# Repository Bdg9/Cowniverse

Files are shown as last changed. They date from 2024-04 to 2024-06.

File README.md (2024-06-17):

# Cowniverse

Welcome to the **Cowniverse** documentation! This prototype originated from the Interactive Game for Children project from the Assistive Technology Challenge. It involves creating a fun game to foster interactions between children with cerebral palsy. The repository is structured into several key components, which are organized into different folders. Below you will find a detailed overview of the contents of each folder.

## Folder Structure

1. **full**
2. **fusion**
3. **library**
4. **test**

### Full Folder

The `full` folder contains the code for the completed prototypes.

- **Prototype 1**: The first complete prototype. This includes all necessary code to run this version.
- **Prototype 2**: The second complete prototype. Similar to Prototype One, this includes all the required code.

### Fusion Folder

The `fusion` folder houses all the CAD files for the different parts of prototype 2. These files can be used for 3D printing or laser cutting the necessary components for the prototype.

- **3d_printed_mounts**: CAD files for the main electronics mounts and the speakers, to 3D print.
- **Box buttons**: CAD files for buttons boxes, to laser cut.
- **Farm**: CAD files for building the farm, to laser cut.
- **Game board**: CAD files for the rounded box, the PET sheet between magnorail and the character and the fixations to close the box, to laser cut.
- **Gate**: CAD files for the gate. The mount for the servos, to laser cut. The sliding mechanism and the mount for the post, to 3d print.
- **Snowboard**: CAD files for snowboards/skates to place the finger puppet on it or a figurine, to 3d print.

### Library Folder

The `library` folder includes the necessary libraries to be installed for the `df_player pro`, which is used in prototype 2. Ensure you install these libraries before running the final prototype.

- **DFPlayer Pro Library**: Download and install this library to ensure proper functionality of the audio components in the prototypes.

### Test Folder

The `test` folder contains Arduino scripts used to test various subsystems of the prototypes. These scripts are helpful for debugging and ensuring each individual subsystem works correctly before integrating them into the full prototypes.

## Contact

For any questions or further information, please contact us one of us :
- Gonçalo Braga : [gbraga2086@gmail.com]
- Barbara De Groot : [irado1999@gmail.com] 
- Loric Emmenegger : [emmenegger.loric@gmail.com]
- Jean-Baptiste Poussin : [poussin.jeanbaptiste@gmail.com]

Happy coding, and welcome to the Cowniverse!

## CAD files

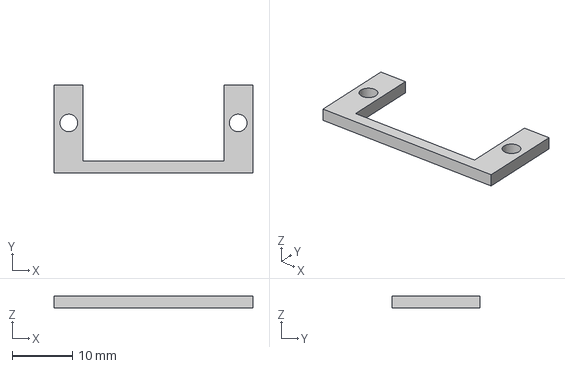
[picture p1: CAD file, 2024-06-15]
fusion/Gate/servo_mount_house.step
32.9 x 14.5 x 2.00 mm

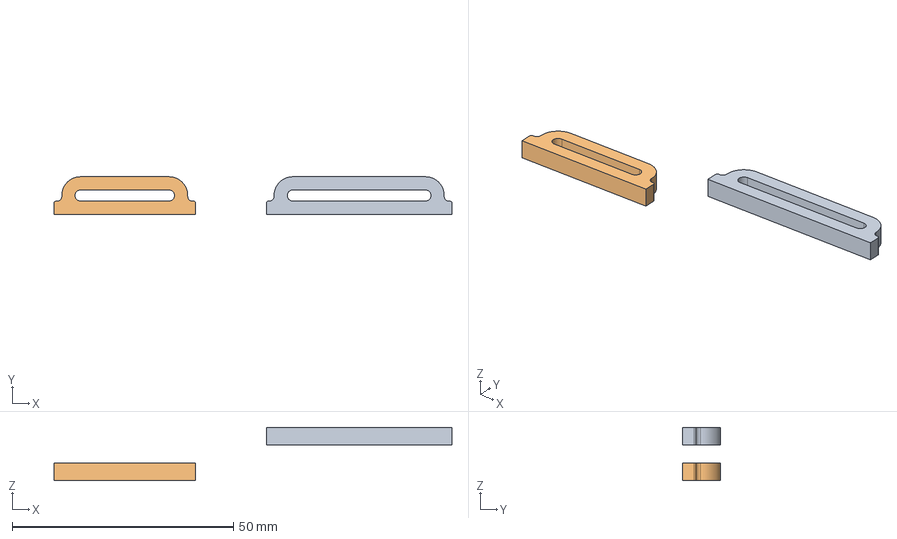
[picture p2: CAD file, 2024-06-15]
fusion/Gate/servo_slide.step
90.0 x 8.50 x 12.0 mm

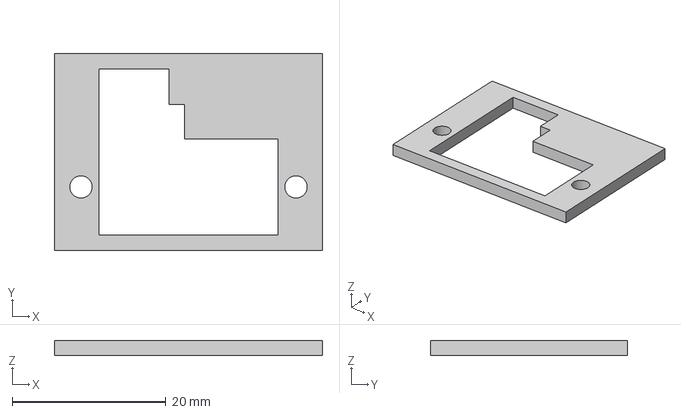
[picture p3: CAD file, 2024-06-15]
fusion/Gate/servo_mount_post.step
34.9 x 25.6 x 2.00 mm

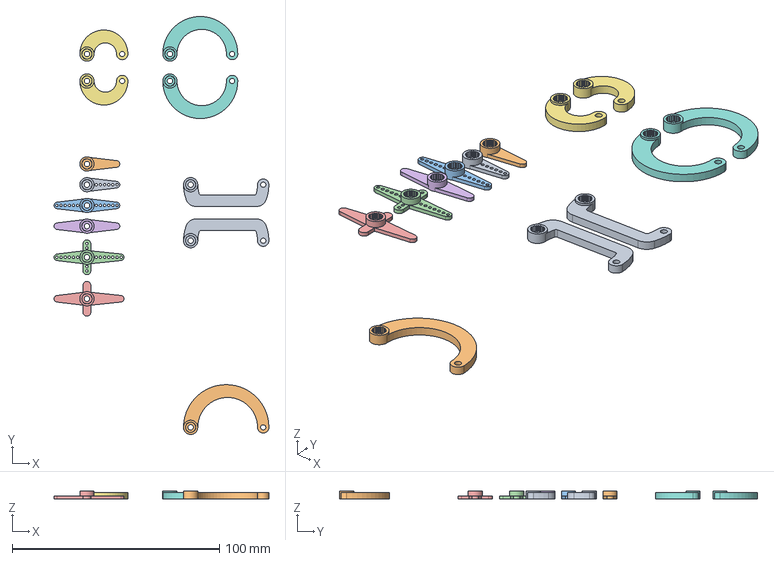
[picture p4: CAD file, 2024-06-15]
fusion/Gate/SG90_Servo_Horn.step
103.6 x 201.6 x 3.82 mm

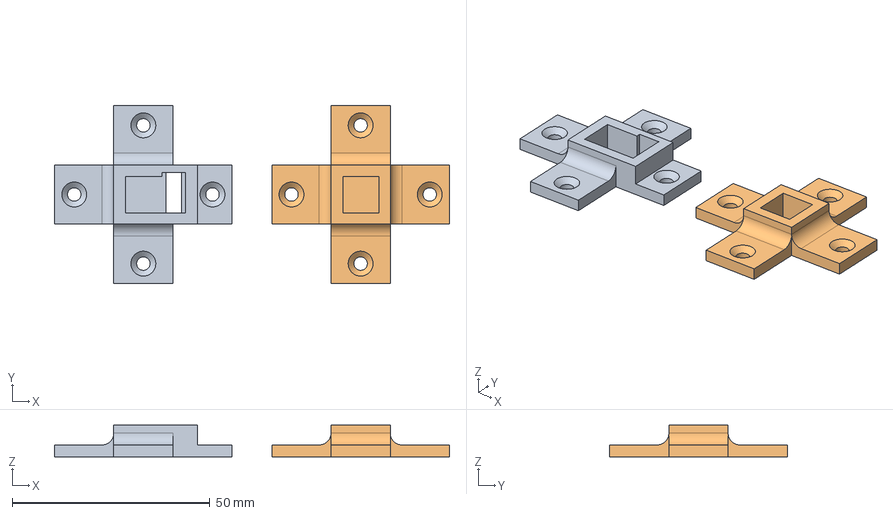
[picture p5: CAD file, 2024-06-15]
fusion/Gate/post_mount.step
100.0 x 45.0 x 8.00 mm

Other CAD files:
fusion/Box buttons/box double button.step
fusion/Game board/Rounded Box/RoundedBox sides.step
fusion/Box buttons/box single button.step
fusion/Game board/MDF_PET_support.step
fusion/Game board/Rounded Box/RoundedBox top.step
fusion/Game board/PET_path.step
fusion/Game board/Rounded Box/RoundedBox bottom.step
fusion/Game board/External_support_grass.step
fusion/Game board/nut_fixation_test.step
fusion/3d_printed_mounts/mount_all.f3d
fusion/3d_printed_mounts/speaker_mount.f3d
fusion/Box buttons/box double button.f3d
fusion/Box buttons/box single button.f3d
fusion/Box buttons/box_engravings.f3d
fusion/Farm/enseignes.f3d
fusion/Farm/mount_farm.f3d
fusion/Farm/servo_mount_farm.f3d
fusion/Farm/socle_toit.f3d
fusion/Farm/toit-dup.f3d
fusion/Farm/toit.f3d
fusion/Farm/toit_maison.f3d
fusion/Game board/External_support_grass.f3d
fusion/Game board/MDF_PET_support.f3d
fusion/Game board/PET_path.f3d
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

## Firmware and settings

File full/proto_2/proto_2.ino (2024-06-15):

#include <Servo.h>
#include "Obstacle.h"
#include "States.h"
#include "House.h"
//librairy audio
#include <DFRobot_DF1201S.h>
//librairy leds
#include <Adafruit_NeoPixel.h>

// Define the motor control pins
#define ENA 6
#define IN1 8
#define IN2 7
#define SPEED 90

// Define buttons pin
#define B_FORWARD 32
#define B_BACKWARD 33
#define B_OBS 34
#define POT A10
#define MODE_1 2
#define MODE_2 3

// Define servos pin
#define BAR_1 11
#define BAR_2 10
#define HOUSE_L 13
#define HOUSE_R 12 

// Define for leds
#define LED_PIN     5     // Pin connecté à la bande de LEDs
#define LED_COUNT   8    // Nombre de LEDs dans la bande
#define BRIGHTNESS 50

//file paths for audio
const char* file_paths_meuh[] = {
    "/meuh/Meuh1.mp3",
    "/meuh/Meuh2.mp3",
    "/meuh/Meuh3.mp3",
    "/meuh/Meuh4.mp3",
    "/meuh/Meuh5.mp3",
    "/meuh/Meuh6.mp3",
    "/meuh/Meuh7.mp3",
    "/meuh/Meuh8.mp3",
};

const char* file_paths_bip[] = {
  "/bipbip/Bip1.mp3",
  "/bipbip/Bip2.mp3",
  "/bipbip/Bip3.mp3",
  "/bipbip/Bip4.mp3",
  "/bipbip/Bip5.mp3",
  "/bipbip/Bip6.mp3",
};

const char* file_paths_groin[] = {
  "/groin/Groin1.mp3",
  "/groin/Groin2.mp3",
  "/groin/Groin3.mp3",
  "/groin/Groin4.mp3",
  "/groin/Groin5.mp3",
  "/groin/Groin6.mp3",
  "/groin/Groin7.mp3",
};

const char* file_paths_cot[] = {
  "/poule/Poule5.mp3",
  "/poule/Poule4.mp3",
  "/poule/Poule3.mp3",
  "/poule/Poule2.mp3",
  "/poule/Poule1.mp3",
};

const char* file_paths_yay[] = {
  "/marley/marley1.mp3",
  "/yay/Hiphoura2.mp3",
  "/yay/Houra1.mp3",
  "/yay/titu.mp3",
  "/yay/Uhou1.mp3",
  "/yay/uhouai.mp3",
  "/yay/uhu.mp3",
  "/yay/vamos.mp3",
  "/yay/Yay1.mp3",
  "/yay/Yay2.mp3",
  "/yay/Yay3.mp3",
  "/yay/Yay4.mp3",
  "/yay/Youpi1.mp3",
  "/yay/Youpi2.mp3",
  "/marley/marley1.mp3",
  "/ohNo/Ohoh1.mp3",
};

const int num_files_meuh = sizeof(file_paths_meuh) / sizeof(file_paths_meuh[0]);
const int num_files_bip = sizeof(file_paths_bip) / sizeof(file_paths_bip[0]);
const int num_files_groin = sizeof(file_paths_groin) / sizeof(file_paths_groin[0]);
const int num_files_yay = sizeof(file_paths_yay) / sizeof(file_paths_yay[0]);
const int num_files_cot = sizeof(file_paths_cot) / sizeof(file_paths_cot[0]);

//debug prints
bool verbose = false;

// Initialiser DFPlayer
DFRobot_DF1201S DF1201S;
int vol;

// Init leds
Adafruit_NeoPixel strip = Adafruit_NeoPixel(LED_COUNT, LED_PIN, NEO_GRB + NEO_KHZ800);


//left door
Servo bar_1_servo;
Obstacle bar_1(bar_1_servo);

//right door
Servo bar_2_servo;
Obstacle bar_2(bar_2_servo);

//house
Servo house_1;
Servo house_2;
House house(house_1, house_2);

//obstacle button
int buttonObsState = LOW;
int buttonObsLastState = LOW;
bool buttonObs = false;

//motor forward button
int buttonForwState = LOW;
int buttonForwLastState = LOW;

//motor backward button
int buttonBackState = LOW;
int buttonBackLastState = LOW;

//motor state
MotorState motorState = STOP;
Sound sound = NONE;
bool bar_1_update = false;
bool bar_2_update = false;
bool house_update = false;

//game mode 
GameMode mode;
Sound character_type;

//detection timer
unsigned long detection_timer = 0;
const unsigned long detection_interval = 500;

void setup() {
  Serial.begin(9600);
  Serial3.begin(115200); //begin serial for audio

  //init gates
  bar_1.init(BAR_1, A1, A0, 50, 165);
  bar_2.init(BAR_2, A3, A2, 165, 50);

  //init house
  house.init(HOUSE_L, HOUSE_R, A4, 60, 10, 8, 50);

  // Set the buttons pin as outputs
  pinMode(B_OBS, INPUT);
  pinMode(B_FORWARD, INPUT);
  pinMode(B_BACKWARD, INPUT);
  pinMode(POT, INPUT);
  pinMode(MODE_1, INPUT_PULLUP);
  pinMode(MODE_2, INPUT_PULLUP);

  // Set the motor control pins as outputs
  pinMode(ENA, OUTPUT);
  pinMode(IN1, OUTPUT);
  pinMode(IN2, OUTPUT);

  //init game mode
  mode = read_mode();

  //choose character type
  int mode_1 = digitalRead(MODE_1);
  int mode_2 = digitalRead(MODE_2);
  if((mode_1 == HIGH) && (mode_2 == HIGH)){
    character_type = COW;
  }else if(mode_2 == HIGH){
    character_type = PIG;
  }else{
    character_type = COT;
  }

  // Set up leds
  strip.begin();
  strip.show(); // Initialise toutes les LEDs à 'off'
  strip.setBrightness(BRIGHTNESS);


  //setup audio
  // Initialisation du DFPlayer
  while(!DF1201S.begin(Serial3)){
    Serial.println("Init failed, please check the wire connection!");
    delay(1000);
  }

  Serial.println("audio ready");
  Serial.print("mode :");
  Serial.println(mode);
  
  //Set volume to 15
  DF1201S.setVol(20);
  //deactivate prompts
  DF1201S.setPrompt(false);
  //Enter music mode
  DF1201S.switchFunction(DF1201S.MUSIC);
  //Set playback mode to "repeat all"
  DF1201S.setPlayMode(DF1201S.SINGLE);

  delay(500);

  //test sensor
  if( (bar_1.get_front_sensor() > THRESHOLD) ||  (bar_1.get_back_sensor() > THRESHOLD) || (bar_2.get_front_sensor() > THRESHOLD) ||
      (bar_2.get_back_sensor() > THRESHOLD) || (house.get_sensor() > THRESHOLD)){
    Serial.println("ERROR : sensor obstructed");
    DF1201S.playFileNum(/*File Number = */2);
    delay(10000);
  }

  DF1201S.playFileNum(/*File Number = */1);
  delay(200);

  
}

void loop() {
  //change volume
  vol = analogRead(POT);            // reads the value of the potentiometer (value between 0 and 1023)
  vol = map(vol, 0, 1023, 0, 30);     // scale it for use with the servo (value between 0 and 180)
  DF1201S.setVol(/*VOL = */vol);

  //change mode
  mode = read_mode();
  
  // check button
  buttonObsState = digitalRead(B_OBS);
  buttonForwState = digitalRead(B_FORWARD);
  buttonBackState = digitalRead(B_BACKWARD);
  
  /*
  //use serial instead of physical buttons
  if (Serial.available() > 0) {
    String receivedText = Serial.readStringUntil('\n'); // Read the incoming data until newline character

    receivedText.trim(); // Remove any leading/trailing whitespace characters
    
    if (receivedText == "f") {
      buttonForwState = HIGH;
    } else if (receivedText == "b") {
      buttonBackState = HIGH;
    } else if (receivedText == "o") {
      buttonObsState = HIGH;
      sound = YAY;
    } else {
      Serial.println("Unknown command: " + receivedText);
    }
  }else{
    buttonObsState = LOW;
    buttonForwState = LOW;
    buttonBackState = LOW;
  }*/

  // check if the button is pressed
  if (buttonObsLastState != buttonObsState){
    if (buttonObsState == HIGH){
      buttonObs = true;
      sound = BIP;
    }
  }else{
    buttonObs = false;
  }

  if (buttonForwLastState != buttonForwState){
    if (buttonForwState == HIGH){
      motorState = FORWARD;
      sound = character_type;
    }
  }

  if (buttonBackLastState != buttonBackState){
    if (buttonBackState == HIGH){
      motorState = BACKWARD;
    }
  }

  //update buttons state
  buttonObsLastState = buttonObsState;
  buttonForwLastState = buttonForwState;
  buttonBackLastState = buttonBackState;


  //update the obstacles
  if (mode == SLOW){
    bar_1_update = bar_1.update(buttonObs, motorState);
    bar_2_update = bar_2.update(buttonObs, motorState);
    house_update = house.update(buttonObs, motorState);

    //stop motors if player is detected and the obstacle is closed
    if ((bar_1_update && !bar_1.get_state()) || (bar_2_update && !bar_2.get_state()) || (house_update && !house.get_state()) || (!house.get_state())){
      motorState = STOP;
    }
  }else{
    bar_1_update = bar_1.update_continuous(buttonObs, motorState);
    bar_2_update = bar_2.update_continuous(buttonObs, motorState);
    house_update = house.update_continuous(buttonObs);
  }

  if (house_update){
    sound = YAY;
  }

  //update leds
  if(bar_1_update || bar_2_update || house_update){
    strip.fill(strip.Color(255, 0, 0)); // Red color
  }else if(DF1201S.getFileName() == "/marley/marley1.mp3"){
    setPattern();
  }else{
    strip.fill(strip.Color(0, 255, 0)); // Green color
  }

  strip.show();
  

  if (verbose){
    //Serial.println(house.get_state());
    /*Serial.print("mode 1 :");
    Serial.print(digitalRead(MODE_1));
    Serial.print("  mode_2 : ");
    Serial.println(digitalRead(MODE_2));*/
    Serial.print("A0 : ");
    Serial.print(analogRead(A0));
    Serial.print("  ");
    Serial.print("A1 : ");
    Serial.print(analogRead(A1));
    Serial.print("  ");
    Serial.print("A2 : ");
    Serial.print(analogRead(A2));
    Serial.print("  ");
    Serial.print("A3 : ");
    Serial.print(analogRead(A3));
    Serial.print("  ");
    Serial.print("A10 : ");
    Serial.print(analogRead(A4));
    Serial.println("  ");
  }

  //update the motors
  

  switch (motorState) {
    case FORWARD:
      analogWrite(ENA, SPEED);
      digitalWrite(IN1, HIGH);
      digitalWrite(IN2, LOW);
      break;
    case BACKWARD:
      analogWrite(ENA, SPEED);
      digitalWrite(IN1, LOW);
      digitalWrite(IN2, HIGH);
      break;
    case STOP:
    default:
      digitalWrite(IN1, LOW);
      digitalWrite(IN2, LOW);
      break;
  }
  
  switch (sound){
    case COT:
      playRandomSong(file_paths_cot, num_files_cot);
      sound = NONE;
      break;
    case PIG:
      playRandomSong(file_paths_groin, num_files_groin);
      sound = NONE;
      break;
    case COW:
      playRandomSong(file_paths_meuh, num_files_meuh);
      sound = NONE;
      break;
    case YAY:
      playRandomSong(file_paths_yay, num_files_yay);
      sound = NONE;
      break;
    case BIP:
      playRandomSong(file_paths_bip, num_files_bip);
      sound = NONE;
      break;
    case NONE:
      break;
  }
  
}

GameMode read_mode(){
  if(digitalRead(MODE_1) == HIGH){
    return SLOW;
  }else if(digitalRead(MODE_2) == HIGH){
    return CONTINUOUS;
  }else{
    return SLOW;
  }
}

void playRandomSong(const char* file_paths[], const int num_files) {
  // Select a random file path from the list
  int randomIndex = random(num_files);
  const char* randomFile = file_paths[randomIndex];

  // Play the selected file
  DF1201S.playSpecFile(randomFile);
}

void setPattern() {
  // Couleurs à utiliser
  uint32_t colors[] = {
    strip.Color(255, 0, 0),   // Rouge
    strip.Color(255, 255, 0), // Jaune
    strip.Color(0, 255, 0)    // Vert
  };

  for (int i = 0; i < strip.numPixels(); i++) {
    strip.setPixelColor(i, colors[i % 3]);
  }
  strip.show();
}

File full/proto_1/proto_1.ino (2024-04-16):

#include <Adafruit_PWMServoDriver.h>                             //Include the PWM Driver library
#include <RF24.h> // download library by TMRh20 last version (1.4.8)

#define DFR 0 //door front right
#define DFL 1 //door front left
#define DHL 2 //door hind left
#define DHR 3 //door hind right
#define GATE 4 //gate
#define DELAY_SERVO 10

#define DIR 8
#define PUL 9

// Radio settings
#define CE_PIN 4
#define CSN_PIN 7
RF24 radio(CE_PIN, CSN_PIN);
const uint64_t address = "Butt1";


Adafruit_PWMServoDriver pwm = Adafruit_PWMServoDriver(0x40);    //Create an object of board 1

int servoMin =  135;        // This is the servos minimum pulse length count (out of 4096)
int servoMax =  360;        // This is the servos maximum pulse length count (out of 4096)
int servoFrequency = 50;    // Servo update frequency, analog servos typically run at ~50 Hz

//default pulse length for servos
int dl_min = 135;
int dl_max = 360;
int dr_min = 235;
int dr_max = 425;
int gate_min = 135;
int gate_max = 270;

//variables for stepper motor 
int x;
int trajet;
int state_bigDome;
int last_state_bigDome = LOW;
const int speed = 2000;
const int bigDome = 2; 
const int nb_rev_trajet_1 = 1890;
const int nb_rev_trajet_2 = 2065;


void setup() {
  // put your setup code here, to run once:
  //servos only to PWM ports
  pwm.begin();             //Start board
  pwm.setOscillatorFrequency(27000000);    //Set the PWM oscillator frequency, used for fine calibration
  pwm.setPWMFreq(servoFrequency);          //Set the servo operating frequency

  // for stepper motor driver
  pinMode(PUL,OUTPUT); // PUL
  pinMode(DIR,OUTPUT); // DIR
  pinMode(bigDome, INPUT);
  // serial
  Serial.begin(9600);
  delay(3000);
  // initialisation trajet n°1
  trajet = 1;
  Serial.println(trajet);
  // direction of rotation
  digitalWrite(DIR,LOW); // direction of rotation

  //puts servos at the right position
  pwm.setPWM(DFR, 0, dr_max);
  delay(10);
  pwm.setPWM(DFL, 0, dl_min);
  delay(10);
  pwm.setPWM(DHR, 0, dr_max);
  delay(10);
  pwm.setPWM(DHL, 0, dl_min);
  delay(10);
  pwm.setPWM(GATE, 0, gate_min);
  delay(500);
  
  if (!radio.begin()) {
    //while (1) {}// hold in infinite loop
      Serial.println("Could not turn radio on");  
  }else{
    Serial.println("Radio successfully turned on, now listening");
  }
  // radio settings
  radio.setPayloadSize(4); // sizeof("Meuh")
  radio.setChannel(108); // 0 to 127
  radio.setPALevel (RF24_PA_LOW); // for now //transmitter power level. To choose RF24_PA_MIN, RF24_PA_LOW, RF24_PA_HIGH, RF24_PA_MAX
  radio.setDataRate (RF24_250KBPS); //exchange rate. To choose RF24_2MBPS, RF24_1MBPS, RF24_250KBPS
  
  //set the address for communication and set module as receiver
  radio.openReadingPipe(0, address); // 0 to 5 is the pipe to be opened 
  radio.startListening();
    

}

void loop() {
  // put your main code here, to run repeatedly:
  state_bigDome = digitalRead(bigDome); //uncomment for physically wired button
  if (radio.available()){
    char text[5] = {0};
    radio.read(&text, sizeof(text));
    Serial.println(text);
    state_bigDome = HIGH;
  }


  if (state_bigDome != last_state_bigDome) { // trajet 1
    if ((trajet == 1) && (state_bigDome == HIGH)) {
      open_hind_doors();
      turn_stepper(nb_rev_trajet_1);
      close_hind_doors();
      trajet = 2;
      state_bigDome = LOW;
    }

    if ((trajet == 2) && (state_bigDome == HIGH)) {
      open_gate_front_doors();
      turn_stepper(nb_rev_trajet_2);
      close_gate_front_doors();
      trajet = 1;    
    }
    delay(50);
  }
  
  last_state_bigDome = state_bigDome;
}

//functions for house doors
void open_front_doors(){
  Serial.println("opening front doors");
  for (int i = 0 ; i <= 225 ; i++){
    pwm.setPWM(DFL, 0, dl_min + i);
    pwm.setPWM(DFR, 0, dr_max - i);
    delay(DELAY_SERVO);
  }
}

void open_hind_doors(){
  for (int i = 0 ; i <= 225 ; i++){
    pwm.setPWM(DHL, 0, dl_min + i);
    pwm.setPWM(DHR, 0, dr_max - i);
    delay(DELAY_SERVO);
  }
}

void close_front_doors(){
  for (int i = 0 ; i <= 225 ; i++){
    pwm.setPWM(DFL, 0, dl_max - i);
    pwm.setPWM(DFR, 0, dr_min + i);
    delay(DELAY_SERVO);
  }
}

void close_hind_doors(){
  for (int i = 0 ; i <= 210 ; i++){
    pwm.setPWM(DHL, 0, dl_max - i);
    pwm.setPWM(DHR, 0, dr_min + i);
    delay(DELAY_SERVO);
  }
}

//functions gate
void open_gate(){
    for (int i = 0 ; i <= 135 ; i++){
    pwm.setPWM(GATE, 0, gate_min + i);
    delay(DELAY_SERVO);
  }
}

void close_gate(){
    for (int i = 0 ; i <= 135 ; i++){
    pwm.setPWM(GATE, 0, gate_max - i);
    delay(DELAY_SERVO);
  }
}

void open_gate_front_doors(){
  for (int i = 0 ; i <= 225 ; i++){
    pwm.setPWM(DFL, 0, dl_min + i);
    pwm.setPWM(DFR, 0, dr_max - i);
    if (i<=135){
      pwm.setPWM(GATE, 0, gate_min + i);
    }
    delay(DELAY_SERVO);
  }
}

void close_gate_front_doors(){
  for (int i = 0 ; i <= 225 ; i++){
    pwm.setPWM(DFL, 0, dl_max - i);
    pwm.setPWM(DFR, 0, dr_min + i);
    if (i<=135){
      pwm.setPWM(GATE, 0, gate_max - i);
    }
    delay(DELAY_SERVO);
  }
}

//functions stepper motor
void turn_stepper(int nb_rev){
  for(x = 0; x < nb_rev; x++) { // set number of revolution
      digitalWrite(PUL,HIGH);  // set high level direction of rotation
      delayMicroseconds(speed); // set rotate speed
      digitalWrite(PUL,LOW); // output low
      delayMicroseconds(speed);
    }
}

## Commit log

2024-04-16 new file : testing code for servos of house doors
2024-04-16 stepper working with push button
2024-04-16 stepper et servos ensemble
2024-04-17 minor changes to button code
2024-05-19 feat: class for obstacle with servo working
2024-05-19 feat: button and sensor to control opening and closing done
2024-05-19 feat: put the working obstacle classes and arduino project in proto_2
2024-05-19 feat: base code done, should be easily scalable
    motor goes back and forth
    motor stops when sensor detects something
    obs controllable only when something is detected
2024-05-19 fix: deleted some prints
    [proto_2.ino]
2024-05-29 house class not working yet but created
    [House.cpp]
2024-06-03 code for the buttons with nano in main box
2024-06-05 Single and double button update
2024-06-12 new servos calbrated
2024-06-15 documentation: included relevant fusion filles for reproducibility
    [External_support_grass.f3d, External_support_grass.step, MDF_PET_support.f3d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]
2024-06-16 cleaned Cad files
    [cow_1.f3d, cow_2.f3d, farm_from_web.f3d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]
